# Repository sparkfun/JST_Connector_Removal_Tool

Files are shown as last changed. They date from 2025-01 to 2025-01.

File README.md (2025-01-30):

SparkFun JST Battery Removal Tool
========================================

SparkFun JST Battery Removal Tool (https://www.sparkfun.com/sparkfun-jst-battery-removal-tool.html)

[*SparkFun JST Battery Removal Tool (TOL-27923)*](https://www.sparkfun.com/sparkfun-jst-battery-removal-tool.html)

The SparkFun JST battery removal tool is a tool to remove a standard 2-pin JST-PH connector (2mm pitch) from its housing! Easily remove a LiPo battery's 2-pin JST-PH female connector using the JST battery removal tool! Save your fingertips from grabbing the connector when wiggling the connector out. Avoid accidentally pinching the wires when using needle nose pliers. Or save your wires from being cut when using a diagonal cutter. Simply slide the tool over the LiPo battery's JST female connector with one hand. With your other hand holding the male connector, pull the JST female connector away to disconnect the battery!

This tool also features a keychain hole at the top. Slide in a keychain ring to keep it with [other tools](https://www.sparkfun.com/u-fl-push-pull-tool.html) in your toolbox! Or even have it hanging on a metal shelf with a [small magnet](https://www.sparkfun.com/magnet-square-0-25.html)! The triangle blocks were adjusted for a loose tolerance but will grip the wings when disconnecting. You can slide the tool from the top or the bottom side. A wire channel was also added for the LiPo battery's wires should you decide to slide the tool in a downward fashion when removing the connector against a table.

This tool is great for users who to swap LiPo batteries for projects. Once the LiPo battery is disconnected, you will need to insert replacement a LiPo battery by hand. The JST battery removal tool is not intended to insert a JST female connector into the male connector. This tool will work for most board designs with the [JST male connector](https://www.sparkfun.com/jst-right-angle-connector-smd-2-pin-black.html) populated on the edge of a board. Certain boards that have the JST male connector port facing toward the inside of the board may have components that will cause an obstruction when using the tool. Connectors that are populated close to the JST connector may also be another obstruction when using the tool.

Note: This part was 3D printed so there might be some slight imperfections from printing.

Note: This tool was remixed from user [firia](https://www.thingiverse.com/thing:4554126/files)! The following changes were made:

* increase height of walls to easily print from a LulzBot 3D printer
* sweet logo of the SparkFun flame
* smaller keychain hole
* channel to guide the wire
* fillet hard corners and edges
* deboss SparkFun logo, name, and version number

Note: Thinking about printing your own? You may need to adjust the 3D models in this repository depending on the 3D printer that you use! For example, the orientation of the keychain hole may not be ideal to print and may need to be adjusted or removed.

Repository Contents
-------------------

* **/3D_Model** - 3D model files for printing (.stl are exported files for 3D printing)
    * **/text_logos_vectors** - vector files used to help label tool and cut logo into shapes

Documentation
--------------

* **[Hookup Guide](https://learn.sparkfun.com/tutorials/single-cell-lipo-battery-care/all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)** - A tutorial about LiPo battery care. This includes information about how to connect and disconnect a LiPo battery's 2-pin JST-PH (2mm) connector.

Product Versions
----------------
* [TOL-27923](https://www.sparkfun.com/sparkfun-jst-battery-removal-tool.html) - v2.1f

Version History
---------------
* v2.0 - firia's design
* v2.1 - increase height of walls to easily print from a modified LulzBot Taz 5 FDM printer; prints after this were used with the FormLabs Form 3 SLA printer
* v2.1a - add sweet logo of SparkFun flame
* v2.1b - add smaller keychain hole, this test print was skipped and not exported to a .stl file
* v2.1c - adjust channel for wire and extend hole to cut through side wall
* v2.1d - adjust triangles by -0.1mm height to slide the tool easier between female JST-PH (LiPo battery) and male (socket) horizontal JST-PH connector
* v2.1e - add fillets; deboss SparkFun logo, product name, version number
* v2.1f - fix hairline gap since shapes were not touching by extending triangles near SparkFun flame; combine shapes and holes for one shell; final print for production!

License Information
-------------------

This product is _**open source**_!

Please review the LICENSE.md file for license information.

If you have any questions or concerns on licensing, please contact technical support on our [SparkFun forums](https://forum.sparkfun.com/viewforum.php?f=152).

Distributed as-is; no warranty is given.

- Your friends at SparkFun.

_<COLLABORATION CREDIT>_

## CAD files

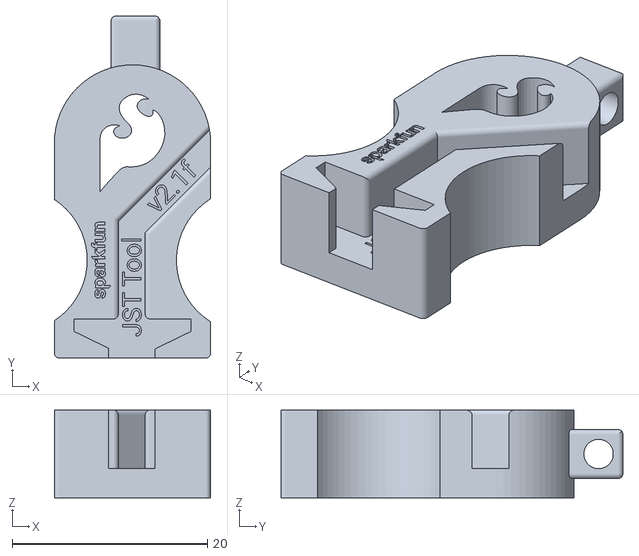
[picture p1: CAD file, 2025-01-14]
3D_Model/SparkFun_JST_removal_tool_v2.1f.stl
16.0 x 35.0 x 9.00

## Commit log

2025-01-04 Upload STL Models and Preform Files
    [JST_removal_tool_v2.1_Mod.stl, JST_removal_tool_v2.1a_Mod.stl, JST_removal_tool_v2.1c_Mod.stl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]
2025-01-06 More Prints
2025-01-14 - Add v2.1f to adjust for custom manufacturing 3d print
    [JST_removal_tool_v2.1f_Mod.stl]
2025-01-16 Copy v2.1f for production
    [JST_removal_tool_v2.1f_Mod - Copy.stl]
2025-01-20 folder rename
    [JST_removal_tool_v2.1_Mod.stl, JST_removal_tool_v2.1a_Mod.stl, JST_removal_tool_v2.1c_Mod.stl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]
2025-01-20 Remove old versions
    [JST_removal_tool_v2.1_Mod.stl, JST_removal_tool_v2.1a_Mod.stl, JST_removal_tool_v2.1c_Mod.stl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]
2025-01-20 File rename with minor version change
    [SparkFun_JST_removal_tool_v2.2.stl]
2025-01-20 Rename to match text on print
    [SparkFun_JST_removal_tool_v2.1f.stl]
